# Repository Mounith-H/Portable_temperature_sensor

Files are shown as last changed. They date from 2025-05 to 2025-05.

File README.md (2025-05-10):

# Portable Temperature Sensor

<div align="center">
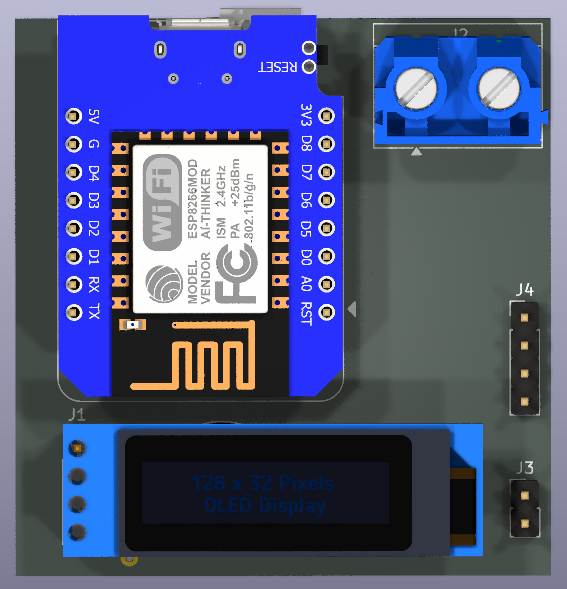
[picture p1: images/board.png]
Pin Connections Table
  
</div>



## Overview

The Portable Temperature Sensor is a wireless IoT temperature monitoring device based on the ESP8266 NodeMCU platform. It uses a MAX6675 thermocouple interface to measure temperatures up to 1024°C with high precision, making it suitable for industrial monitoring, cooking, 3D printing, and scientific applications.

### Key Features

- **High-Temperature Measurement:** Uses the MAX6675 thermocouple for accurate measurements up to 1024°C
- **Wireless Connectivity:** Built-in WiFi for remote monitoring and control
- **MQTT Support:** Integrates with home automation systems and custom dashboards
- **Alarm System:** Configurable temperature thresholds with buzzer alerts
- **Interrupt Output:** Provides digital signal output when temperature exceeds thresholds
- **Custom PCB Design:** Optimized layout with full KiCad design files
- **Serial Communication:** Both USB and software serial interfaces for flexible integration

## Hardware Components

- **NodeMCU ESP8266** - Main controller with WiFi capability
- **MAX6675 Module** - K-type thermocouple interface
- **K-Type Thermocouple** - High-temperature sensing element
- **Buzzer** - For audible alerts
- **Passive Components** - Resistors, capacitors for circuit stability

## Pin Connections

| Pin Numbers | Pin Names | Pin Function | Other | Connection |
|---|---|---|---|---|
| ADC0 | A0 | Analog Input | X | X |
| GPIO16 | D0 | WAKE | X | SEN-CS |
| GPIO5 | D1 | SCL | X | OLED/ SCL |
| GPIO4 | D2 | SDA | X | OLED/ SDA |
| GPIO0 | D3 | FLASH | Pull-up  | BUZZER |
| GPIO2 | D4 | TXD1/LED | Pull-up  | INTERRUPT |
| GPIO14 | D5 | SCLK | X | SEN-SCK |
| GPIO12 | D6 | MISO | X | SEN-SO |
| GPIO13 | D7 | MOSI/RXD2 | X | UART-RX |
| GPIO15 | D8 | CS/TXD2 | Pull-down| UART-TX |
| GPIO3 | RX | RXD0 | X | X |
| GPIO1 | TX | TXD0 | X | X |
| RST | RST | Reset | Pull-up  | X |

## Software Setup

### Prerequisites

- [PlatformIO](https://platformio.org/) (recommended) or Arduino IDE
- Required libraries:
  - PubSubClient for MQTT
  - EspSoftwareSerial for additional serial ports
  - Adafruit MAX6675 for thermocouple interface
  - GyverOLED for display support (optional - will be implemented separately)

### Installation

1. Clone this repository:
   ```
   git clone https://github.com/MOUNITH-H/Portable_temperature_sensor.git
   ```

2. Open the project in PlatformIO or Arduino IDE:
   - For PlatformIO: Open the `Portable_temperature_sensor` folder
   - For Arduino IDE: Open `src/main.cpp` as your sketch

3. Configure WiFi and MQTT settings:
   - Edit the connection parameters in `main.cpp`

4. Build and upload to your NodeMCU

## PCB Design

The project includes a custom PCB design created with KiCad. The design files are in the `pcb` folder:

- Full schematic in `pcb.kicad_sch`
- PCB layout in `pcb.kicad_pcb`
- Interactive BOM available in `pcb/bom/ibom.html`

## Usage

1. Power the device using USB or a 5V power source
2. The device will automatically connect to the configured WiFi network
3. Temperature data is published to the MQTT topic `portable_temp_sensor/temperature`
4. The buzzer will sound if the temperature exceeds the configured threshold
5. Configure alarm settings via the MQTT topic `portable_temp_sensor/settings`

## MQTT Topics

| Topic | Description | Message Format |
|---|---|---|
| `portable_temp_sensor/temperature` | Current temperature readings | `{"temp": 25.4, "timestamp": 1620123456}` |
| `portable_temp_sensor/settings` | Device configuration | `{"threshold": 80, "buzzer_enabled": true}` |
| `portable_temp_sensor/status` | Device status information | `{"uptime": 3600, "wifi_strength": -67}` |

## Troubleshooting

- **No temperature readings:** Check thermocouple connections
- **Cannot connect to WiFi:** Verify credentials in the code
- **MQTT connection issues:** Confirm server address and port settings
- **Erratic readings:** Check for interference with thermocouple wires

## TODO
- [ ] Convert to FreeRTOS

## Contributing

Contributions are welcome! Please feel free to submit a Pull Request.

## License

This project is licensed under the MIT License - see the [LICENSE](LICENSE) file for details.

## Author

- **MOUNITH H** - *Initial work*

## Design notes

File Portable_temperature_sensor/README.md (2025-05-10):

# Portable Temperature Sensor - Implementation

This folder contains the implementation code for the Portable Temperature Sensor project.

## Project Structure

```
Portable_temperature_sensor/
├── platformio.ini        # PlatformIO configuration file
├── include/              # Header files
├── lib/                  # Project-specific libraries
├── src/                  # Source code
│   ├── main.cpp          # Main application code
│   ├── NetworkManager.h  # WiFi connection management
│   ├── display_helper.h  # Display helper functions (not currently used)
│   └── display_helper.cpp# Display implementation (not currently used)
└── test/                 # Test files
```

## Development Environment

### PlatformIO Configuration

This project uses PlatformIO for dependency management and deployment. The `platformio.ini` file is configured with:

```ini
[env:nodemcuv2]
platform = espressif8266
board = nodemcuv2
framework = arduino
monitor_speed = 115200
lib_deps = 
	knolleary/PubSubClient@^2.8
	plerup/EspSoftwareSerial@^8.2.0
	adafruit/MAX6675 library@^1.1.2
	gyverlibs/GyverOLED@^1.6.4
```

> **Note:** The GyverOLED library is still included but display functionality has been removed in the latest version. This dependency will be removed in future updates.

## Implementation Details

### Hardware Configuration

The sensor hardware is configured in `main.cpp` with the following pin assignments:

```cpp
// MAX6675 thermocouple interface pins
const int thermoDO = 12;   // Data out (SO/MISO)
const int thermoCS = 16;   // Chip select
const int thermoCLK = 14;  // Clock signal

// Output pins
const int buzzerPin = 0;     // Alarm buzzer
const int interruptPin = 2;  // External trigger signal

// Software serial port
const int SOFT_RX = 13;  // GPIO13 (D7)
const int SOFT_TX = 15;  // GPIO15 (D8)
```

### Network Connectivity

WiFi connection is managed through the `NetworkManager` class in `src/NetworkManager.h`, which provides:

- Automatic reconnection handling
- Connection state management
- Status reporting

### MQTT Integration

Temperature data is published to MQTT topics, with the following features:
- Automatic reconnection to MQTT broker
- Configurable publishing interval
- JSON-formatted messages for easier parsing

## Building and Running

### Using PlatformIO

1. Open this folder in VSCode with PlatformIO extension
2. Build the project:
   ```
   platformio run
   ```
3. Upload to NodeMCU:
   ```
   platformio run --target upload
   ```
4. Monitor serial output:
   ```
   platformio device monitor
   ```

### Using Arduino IDE

1. Rename `main.cpp` to `Portable_temperature_sensor.ino`
2. Install required libraries through the Arduino Library Manager
3. Set board to "NodeMCU 1.0 (ESP-12E Module)"
4. Upload sketch

## Configuration

To configure the device, edit the following parameters in `src/main.cpp`:

```cpp
// WiFi settings
const char* ssid = "YOUR_WIFI_SSID";
const char* password = "YOUR_WIFI_PASSWORD";

// MQTT settings
const char* mqtt_server = "YOUR_MQTT_SERVER";
const int mqtt_port = 1883;

// Temperature thresholds
const float tempThreshold = 80.0;  // Temperature alarm threshold in °C
```

## Known Issues

1. After power loss, device requires manual configuration

---

For full project documentation, including hardware details and usage instructions, see the [main README](../README.md) in the parent directory.

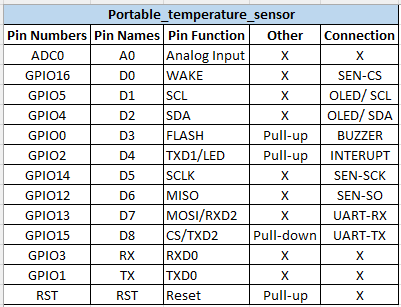
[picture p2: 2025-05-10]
images/Connections_Table.png

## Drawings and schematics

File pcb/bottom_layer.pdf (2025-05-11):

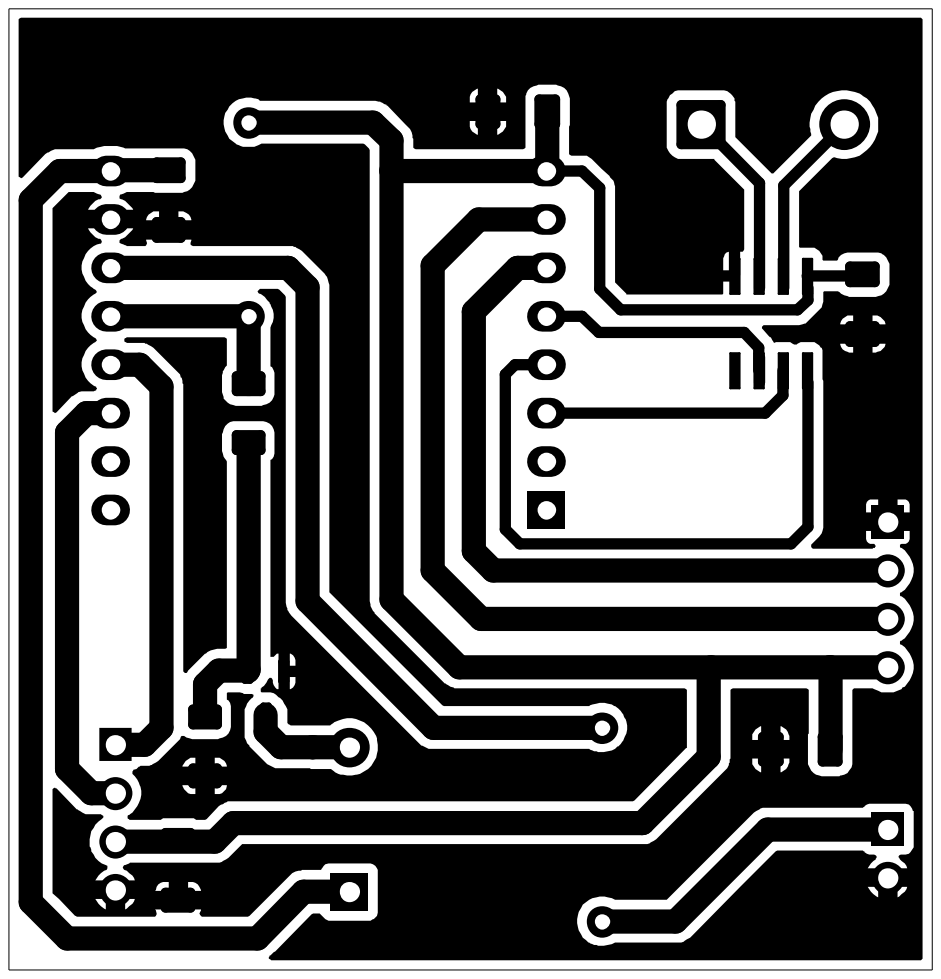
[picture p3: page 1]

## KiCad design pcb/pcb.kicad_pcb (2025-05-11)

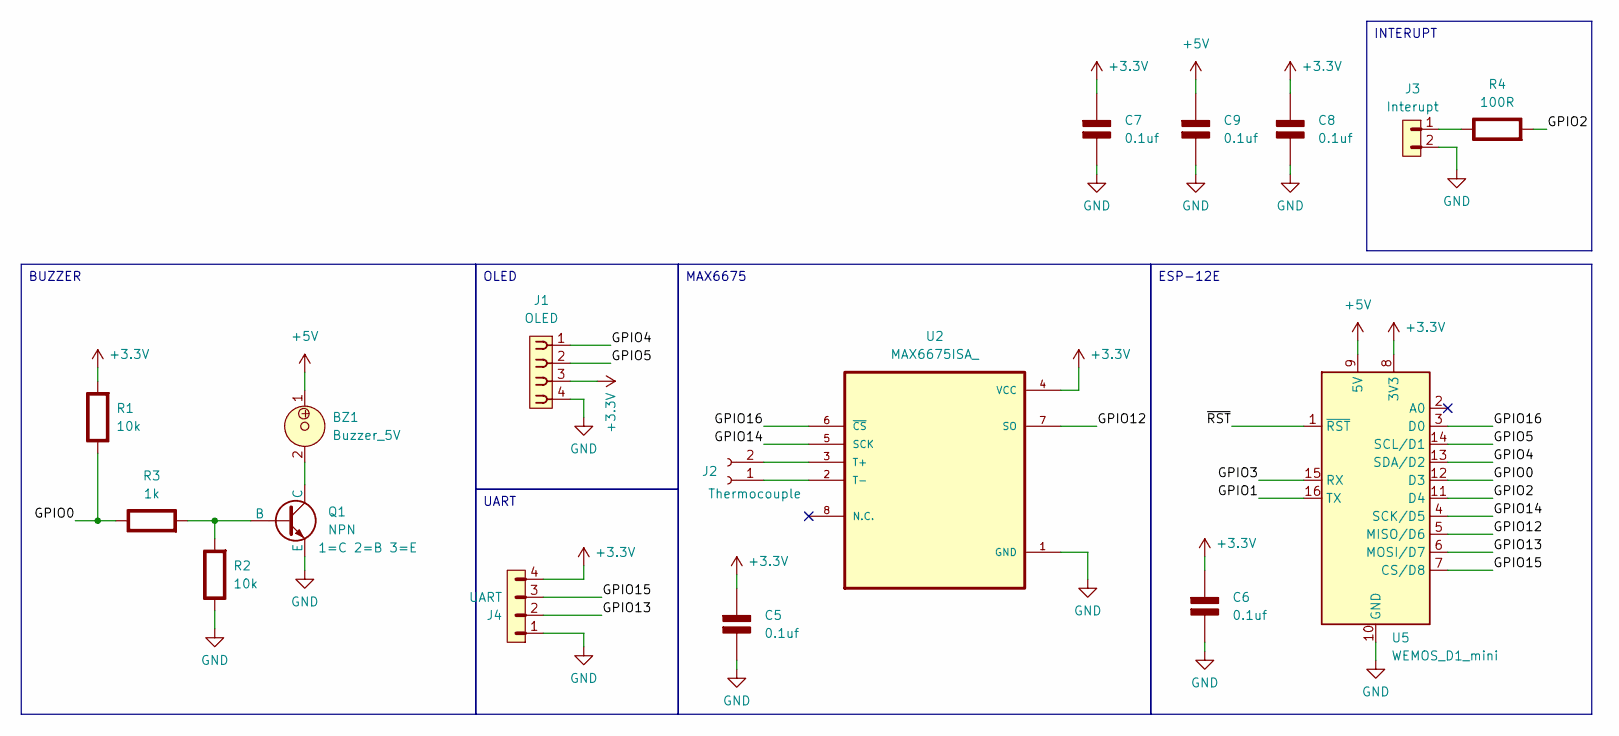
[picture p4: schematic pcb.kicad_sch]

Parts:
BZ1: Buzzer_5V; Buzzer_12x9.5RM7.6
C5, C6, C7, C8, C9: 0.1uf; C_1206_3216Metric_Pad1.33x1.80mm_HandSolder; Rating V
J1: OLED; PinSocket_1x04_P2.54mm_Vertical
J2: Thermocouple; TerminalBlock_MetzConnect_Type175_RT02702HBLC_1x02_P7.50mm_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
J3: Interupt; PinHeader_1x02_P2.54mm_Vertical
J4: UART; PinHeader_1x04_P2.54mm_Vertical
Q1: NPN; SOT-23-3
R1: 10k; R_Axial_DIN0207_L6.3mm_D2.5mm_P10.16mm_Horizontal; Rating W
R2: 10k; R_1206_3216Metric_Pad1.30x1.75mm_HandSolder; Rating W
R3: 1k; R_1206_3216Metric_Pad1.30x1.75mm_HandSolder; Rating W
R4: 100R; R_Axial_DIN0207_L6.3mm_D2.5mm_P10.16mm_Horizontal; Rating W
U2: MAX6675ISA_; MAX6675ISA__SOIC127P600X175-8N
U5: WEMOS_D1_mini; WEMOS_D1_mini_light

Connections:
+3.3V: C5.1 (+), C6.1 (+), C7.1 (+), C8.1 (+), J1.3, J4.4, R1.2 (-), U2.4 (VCC), U5.8 (3V3)
+5V: BZ1.1, C9.1 (+), U5.9 (5V)
/GPIO0: R1.1 (+), R3.1 (+), U5.12 (D3)
/GPIO1: U5.16 (TX)
/GPIO2: R4.2 (-), U5.11 (D4)
/GPIO3: U5.15 (RX)
/GPIO4: J1.1, U5.13 (SDA/D2)
/GPIO5: J1.2, U5.14 (SCL/D1)
/GPIO12: U2.7 (SO), U5.5 (MISO/D6)
/GPIO13: J4.2, U5.6 (MOSI/D7)
/GPIO14: U2.5 (SCK), U5.4 (SCK/D5)
/GPIO15: J4.3, U5.7 (CS/D8)
/GPIO16: U2.6 (~CS), U5.3 (D0)
/~RST: U5.1 (~RST)
GND: C5.2 (-), C6.2 (-), C7.2 (-), C8.2 (-), C9.2 (-), J1.4, J3.2, J4.1, Q1.3 (E), R2.1 (+), U2.1 (GND), U5.10 (GND)
unnamed: J2.1, U2.2 (T-)
unnamed: J2.2, U2.3 (T+)
unnamed: Q1.2 (B), R2.2 (-), R3.2 (-)
unnamed: BZ1.2, Q1.1 (C)
unnamed: J3.1, R4.1 (+)

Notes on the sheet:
UART
BUZZER
MAX6675
INTERUPT
ESP-12E
OLED

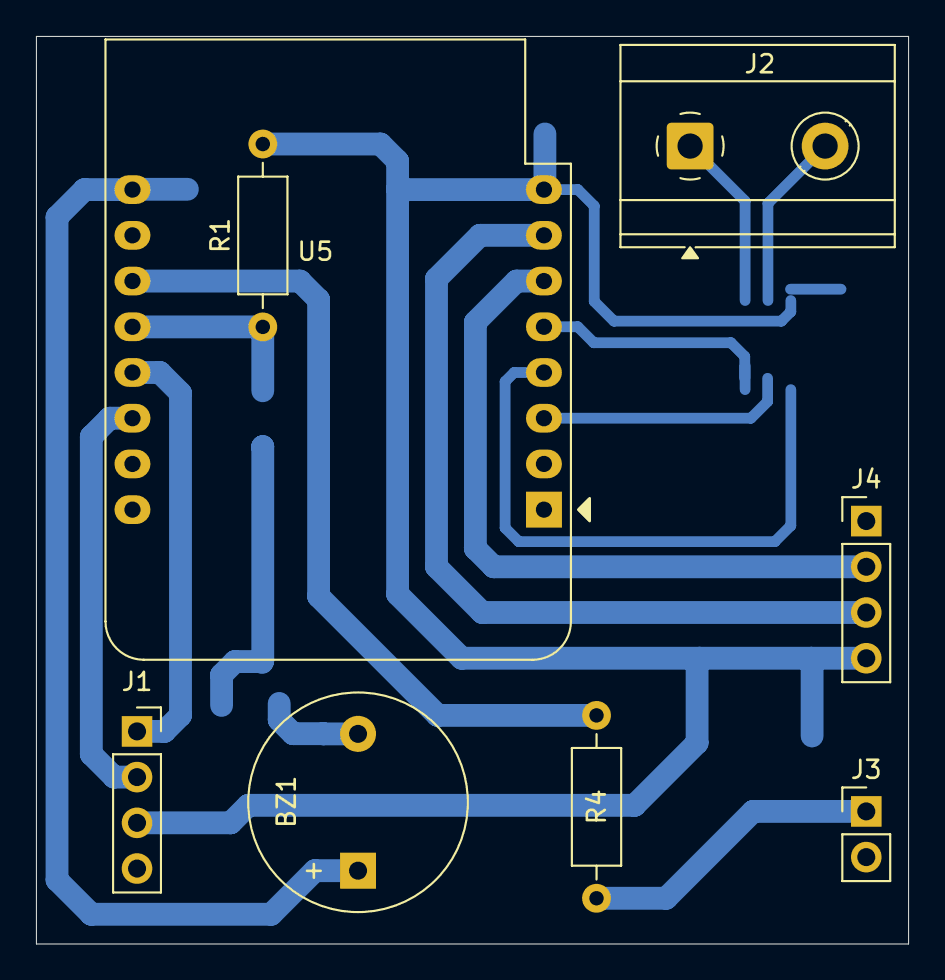
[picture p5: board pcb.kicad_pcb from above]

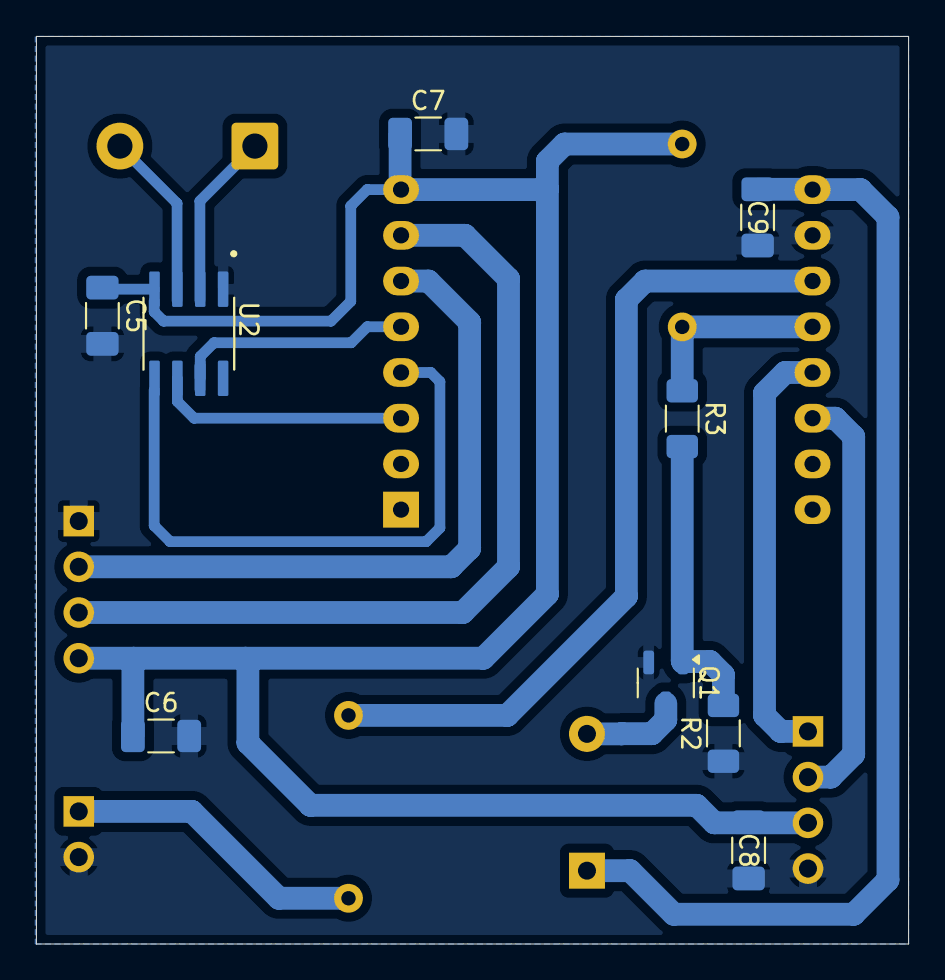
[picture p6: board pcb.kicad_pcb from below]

Board: 2 copper layers, 48.5 x 50.4 mm, 17 parts (9 on the bottom side), 17 nets.

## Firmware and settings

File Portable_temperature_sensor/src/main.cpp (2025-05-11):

#include <Arduino.h>
#include <ESP8266WiFi.h>
#include <PubSubClient.h>
#include <SoftwareSerial.h>
#include <time.h>
#include <max6675.h>
#include <GyverOLED.h>
#include "NetworkManager.h"
#include "display_helper.h"
#include "splashScreen.h"

/*
HARDWARE CONNECTIONS:

MAX6675 Thermocouple:
- SO  → GPIO12 (D6)  // Data from sensor
- CS  → GPIO16 (D0)  // Chip select
- SCK → GPIO14 (D5)  // Clock signal

OLED Display (I2C):
- SDA → GPIO4  (D2)
- SCL → GPIO5  (D1)

Peripherals:
- Buzzer   → GPIO0  (D3)  // Alarm when temperature exceeds threshold
- Interrupt → GPIO2  (D4)  // External trigger signal

Communication:
- Software Serial: RX→GPIO13 (D7), TX→GPIO15 (D8)  // For external comms
- Hardware Serial: USB port (115200 baud)          // For debugging

Power Requirements:
- All components operate at 3.3V
- Connect all GND pins to common ground
*/

// External communication port (separate from debug serial)
const int SOFT_RX = 13;  // GPIO13 (D7)
const int SOFT_TX = 15;  // GPIO15 (D8)
SoftwareSerial softSerial(SOFT_RX, SOFT_TX);

// MAX6675 thermocouple interface pins
const int thermoDO = 12;   // Data out (SO/MISO)
const int thermoCS = 16;   // Chip select
const int thermoCLK = 14;  // Clock signal
MAX6675 thermocouple(thermoCLK, thermoCS, thermoDO);

// Output pins
const int buzzerPin = 0;     // Alarm buzzer
const int interruptPin = 2;  // External trigger signal

// Wi-Fi & MQTT configuration (fill these in)
const char* ssid         = "********";        // FIXME: replace with your wifi SSID
const char* password     = "********";        // FIXME: replace with your wifi password
const char* mqtt_server  = "192.168.137.1";   // FIXME: replace with your mqtt server IP
const int   mqtt_port    = 1883;              // replace with your mqtt server port default is 1883
const char* mqtt_user    = "***test***";      // FIXME: replace with your mqtt username
const char* mqtt_pass    = "***test***";      // FIXME: replace with your mqtt password

WiFiClient espClient;
PubSubClient mqttClient(espClient);
NetworkManager networkManager(ssid, password);

// OLED display definitions (I2C PCB: SDA=GPIO4, SCL=GPIO5)
#define SCREEN_WIDTH 128
#define SCREEN_HEIGHT 32
#define OLED_WHITE 1  // Color constant for drawing in white
#define OLED_BLACK 0  // Color constant for drawing in black
int currentX, currentY, currentScale; // Track cursor position and text scale

// Initialize OLED display with SSD1306 driver (128x32 resolution)
// using buffered mode for smoother updates, at I2C address 0x3C
GyverOLED<SSD1306_128x32, OLED_BUFFER> display(0x3C);

// OLED Display Settings
unsigned long mainDisplayUpdateInterval = 1000; // Update display every 1 second
unsigned long mainLastDisplayUpdateInterval = 0;

// Battery voltage monitoring 
float batteryVoltage = 0.0; // Battery voltage in volts
int batteryPercentage = 0.0; // Battery percentage (0-100%)
unsigned long lastBatteryUpdate = 0;
const unsigned long batteryUpdateInterval = 1000; // Update battery status every 1 seconds
bool batteryIndicatorToggle = false; // Flag to toggle battery indicator on display

// WiFi and MQTT state tracking
bool mqttWasConnected = false;
unsigned long lastDisplayUpdate = 0;
const unsigned long displayUpdateInterval = 500; // Update network status on display every 1 seconds
bool updateDisplayStatus = false;

// Time configuration
const char* ntpServer = "pool.ntp.org";
const long  gmtOffset_sec = 19800;  // GMT +5:30 for IST // FIXME: Update gmt offset of your location
const int   daylightOffset_sec = 0;
String outputMode = "normal";  // Default output mode

// Data configuration
unsigned long sendInterval  = 1000; // ms between sends
double        thresholdTemp = 80.00;   // °C setpoint
unsigned long lastSendTime  = 0;

// Buzzer control
bool buzzerEnabled = true;        // Global flag to enable/disable buzzer
unsigned long buzzerSilenceUntil = 0;  // Timestamp until when the buzzer should be silenced

// MQTT activity tracking
unsigned long lastMqttUpload = 0;    // Last time data was uploaded
unsigned long lastMqttDownload = 0;  // Last time data was downloaded
const unsigned long mqttActivityIndicatorDuration = 100; // How long to show upload/download activity (ms)

// Global variables
static double tempValue = 0;
bool otherUpdate = true;

// Forward declarations
void mqttCallback(char* topic, byte* payload, unsigned int length);
bool mqttReconnect(int maxAttempts = 3);
void playBuzzerAlarm(double temperature, double threshold); // Control buzzer based on temperature
void updateNetworkDisplay(); // Update network status on display
void logodisplay(); // Display logo on OLED
void displayUpdate(); // Update display with temperature and settings
void serialHandler(); // Handle incoming serial data
void batteryMonitor(); // Monitor battery voltage

void setup() {  
  // Initialize both serial ports
  Serial.begin(115200);     // Hardware Serial for debug
  softSerial.begin(9600);   // Software Serial for communication with external device
  Serial.println("Debug: Serial ports initialized");
  
  // Configure output pins for buzzer and interrupt signals
  pinMode(buzzerPin, OUTPUT);
  pinMode(interruptPin, OUTPUT);
  digitalWrite(interruptPin, LOW); // Initialize interrupt signal as inactive
  
  noTone(buzzerPin);              // Initialize buzzer in silent state
  // MAX6675 automatically initializes when the object is created
  // I2C init for OLED
  Wire.begin(4, 5);
  Wire.setClock(400000);  // Set I2C clock speed to 400kHz (fast mode)
  display.init();                 // Initialize the display
  display.clear();                // Clear the display buffer - necessary to start with a clean black background
  display.setScale(1);            // Set text size scaling to 1 (equivalent to setTextSize)
  display.autoPrintln(true);      // Enable automatic line breaks
  display.invertText(false);      // Ensure text isn't inverted (text is white on black background)
  display.textMode(BUF_REPLACE);  // Ensure text writes in replace mode (not overlaid)

  logodisplay();  // Display animated logo on OLED

  // Initialize network manager (non-blocking)
  networkManager.begin();
  networkManager.startConnection();  // Define version and device info
  const String VERSION = "1.1.0";
  const String DEVICE_ID = "ESP-" + String(ESP.getChipId(), HEX);

  // Show startup message
  display.clear();
  display.setScale(2);
  display.setCursor(57, 0);
  display.print("MEL");
  display.setScale(1);
  display.setCursor(0, 2);
  display.print("Temp Sensor v");
  display.print(VERSION);
  display.setCursor(0, 3); // line 1 (GyverOLED uses line-based cursor position)
  display.print("ID: ");
  display.print(DEVICE_ID);
  display.update(); // update display (equivalent to display.display())

  // Print startup info to Serial  
  Serial.println("\n=========================");
  Serial.println("Temperature Sensor v" + VERSION);
  Serial.println("Device ID: " + DEVICE_ID);
  Serial.println("Sensor: MAX6675 (Digital)");
  Serial.println("Connecting to WiFi: " + String(ssid));
  Serial.println("MQTT Server: " + String(mqtt_server) + ":" + String(mqtt_port));
  
  // Test MAX6675 reading
  float initialTemp = thermocouple.readCelsius();
  Serial.print("Initial temperature reading: ");
  Serial.print(initialTemp);
  Serial.println("°C");
  Serial.println("=========================");
  
  // Configure time (it will sync once WiFi is available)
  configTime(gmtOffset_sec, daylightOffset_sec, ntpServer);
  
  // MQTT setup (connection will happen in loop)
  mqttClient.setServer(mqtt_server, mqtt_port);
  mqttClient.setCallback(mqttCallback);

  delay(1500);
  display.clear();
  display.line(0,16,128,16,OLED_WHITE);
  display.update(); // Clear display after startup message
}

// Update network status display without blocking
// Shows connection status and activity indicators through small dots on display
void updateNetworkDisplay() {
  // MQTT upload activity indicator in top-right corner (data sent to broker)
  if (millis() - lastMqttUpload < mqttActivityIndicatorDuration) {display.dot(127, 0, OLED_WHITE); display.update(127, 0, 127, 0);} 
  else {display.dot(127, 0, OLED_BLACK);  display.update(127, 0, 127, 0);} 

  // Return if it's not time for the next status update
  if (millis() - lastDisplayUpdate < displayUpdateInterval) {
   return;  // Not time to update yet
  }
  lastDisplayUpdate = millis();
  updateDisplayStatus = !(updateDisplayStatus);  // Toggle blink state

  ConnectionState state = networkManager.getState();
  bool mqttConnected = mqttClient.connected();
  
  // Make sure we're not overlapping with other display operations
  display.textMode(BUF_REPLACE);  // Ensure text writes in replace mode (not overlaid)

  // Draw the status indicators one by one
  // MQTT status indicator
  if (mqttConnected) {
    display.dot(127, 4, OLED_WHITE);  // MQTT dot
  } else if (state == CONN_CONNECTED) {
    // MQTT disconnected but WiFi connected - blink
    if (!updateDisplayStatus) display.dot(127, 4, OLED_BLACK); 
    else display.dot(127, 4, OLED_WHITE); 
  } else if ((state == CONN_DISCONNECTED) || (state == CONN_CONNECTION_FAILED)) display.dot(127, 4, OLED_BLACK);

  // WiFi status indicator
  if (state == CONN_CONNECTED) {
    display.dot(127, 8, OLED_WHITE);  // WiFi dot
  } else if (state == CONN_CONNECTING) {
    // Blinking WiFi indicator 
    if (!updateDisplayStatus) display.dot(127, 8, OLED_BLACK); 
    else display.dot(127, 8, OLED_WHITE); 
  } else if ((state == CONN_DISCONNECTED) || (state == CONN_CONNECTION_FAILED)) display.dot(127, 8, OLED_BLACK);

  // Use partial update to only refresh the status indicator area
  display.update(127, 4, 127, 8);  // Update only the status indicator region
  
}

// Non-blocking MQTT reconnect helper
#define CLIENT_ID_LEN 24
bool mqttReconnect(int maxAttempts) {
  if (!networkManager.isConnected()) {
    return false;  // Can't connect to MQTT without WiFi
  }

  static int attempts = 0;
  static unsigned long lastAttemptTime = 0;
  const unsigned long attemptInterval = 1000;  // 1 second between attempts
  
  if (!mqttClient.connected()) {
    unsigned long now = millis();
    
    if (now - lastAttemptTime > attemptInterval) {
      lastAttemptTime = now;
      
      if (attempts < maxAttempts) {
        Serial.print("Debug: MQTT attempt ");
        Serial.println(attempts + 1);
        
        char clientId[CLIENT_ID_LEN];
        snprintf(clientId, CLIENT_ID_LEN, "NodeMCU-%lu", millis());
        if (mqttClient.connect(clientId, mqtt_user, mqtt_pass)) {
          mqttClient.subscribe("sensor/interval");
          mqttClient.subscribe("sensor/setpoint");
          mqttClient.subscribe("sensor/buzzer");  // Add buzzer control topic
          attempts = 0;  // Reset counter on success
          return true;
        } else {
          Serial.print("MQTT connection failed, state=");
          Serial.print(mqttClient.state());
          Serial.print(", attempt ");
          Serial.print(attempts + 1);
          Serial.print("/");
          Serial.println(maxAttempts);
          attempts++;
        }
      } else {
        attempts = 0;  // Reset for next time
        return false;
      }
    }
  } else {
    attempts = 0;  // Reset counter when connected
    return true;
  }
  
  return false;
}

// Main program loop - handles network, display, serial commands, and sensor readings
// Uses non-blocking approach to ensure responsive operation
void loop() {
  // Core functionality handling
  networkManager.update();    // Update network state (non-blocking)
  updateNetworkDisplay();     // Update network status on display (non-blocking)
  serialHandler();            // Handle incoming serial data (non-blocking)
  batteryMonitor();           // Monitor battery voltage (non-blocking)
  // Check if WiFi just connected and print status
  if (networkManager.justConnected()) {
    Serial.println("\n=========================");
    Serial.print("WiFi CONNECTED to: ");
    Serial.println(ssid);
    Serial.print("IP address: ");
    Serial.println(networkManager.getLocalIP());
    Serial.println("=========================");
  }
  
  // MQTT connection management (only if WiFi connected)
  if (networkManager.isConnected()) {
    if (!mqttClient.connected()) {
      // Try reconnect without blocking if not connected
      if (!mqttWasConnected || (millis() % 10000) < 10) {  // First connect or try every ~10 seconds
        bool justConnected = mqttReconnect(1);  // Quick single attempt
        
        // Check if MQTT just connected and print status
        if (justConnected && !mqttWasConnected) {          Serial.println("\n=========================");
          Serial.print("MQTT CONNECTED to broker: ");
          Serial.print(mqtt_server);
          Serial.print(":");
          Serial.println(mqtt_port);
          Serial.println("Subscribed to sensor/interval, sensor/setpoint, and sensor/buzzer");
          Serial.println("Publishing to sensor/temperature");
          Serial.println("MQTT activity indicators: TX (↑), RX (↓) in display corners");
          Serial.println("=========================");
        }
        
        mqttWasConnected = justConnected;
      }
    } else {
      mqttClient.loop();
      
      // If MQTT just became connected
      if (!mqttWasConnected) {
        Serial.println("\n=========================");
        Serial.println("MQTT connection restored");
        Serial.println("=========================");
        mqttWasConnected = true;
      }
    }  
  } 
  else if (mqttWasConnected) {
    Serial.println("\n=========================");
    Serial.println("MQTT DISCONNECTED (WiFi lost)");
    Serial.println("=========================");
    mqttWasConnected = false;  // Reset when WiFi disconnects
  }

  // Store latest temperature reading
  static double tempC = 0.0;
  
  // Periodic temperature read & send
  unsigned long now = millis();
  if (now - lastSendTime >= sendInterval) {
    lastSendTime = now;
      
    // Read MAX6675 temperature
    tempC = thermocouple.readCelsius();  // Direct reading in Celsius
    tempValue = tempC;
    // Get current time (for timestamping in log mode)
    time_t now;
    struct tm timeinfo;
    time(&now);
    localtime_r(&now, &timeinfo);

    // Format and send output based on mode    
    if (outputMode.equals("log")) {
      softSerial.printf("%02d,%02d,%04d,%02d,%02d,%02d,%.2f\n",
                        timeinfo.tm_mday,
                        timeinfo.tm_mon + 1,
                        timeinfo.tm_year + 1900,
                        timeinfo.tm_hour,
                        timeinfo.tm_min,
                        timeinfo.tm_sec,
                        tempC);
    } else if(outputMode.equals("normal")) {
      softSerial.printf("%.2f\n", tempC);
    }    
    
    if (networkManager.isConnected() && mqttClient.connected()) {
      char buf[16];
      dtostrf(tempC, 0, 1, buf);
      
      // Publish temperature and update upload indicator      
      if (mqttClient.publish("sensor/temperature", buf)) {
        lastMqttUpload = millis(); // Mark upload activity time
      }    
    }
      // Control buzzer and interrupt pin based on temperature    
    playBuzzerAlarm(tempC, thresholdTemp);
  }

  displayUpdate();            // Update display 
}

// Handle incoming serial commands from both software and hardware serial
void serialHandler() {
  if (softSerial.available() || Serial.available()) {
    // Read from Software Serial if available, else from Hardware Serial
    String cmd = (softSerial.available()) ? softSerial.readStringUntil('\n') : Serial.readStringUntil('\n');
    cmd.trim(); 
    Serial.print("Command:");
    Serial.println(cmd);   

    if (cmd.equals("log")) {
      outputMode = "log";
      Serial.println("Debug: Switched to Log mode");
    } 
    else if (cmd.equals("normal")) {
      outputMode = "normal";
      Serial.println("Debug: Switched to Normal mode");
    } 
    else if (cmd.startsWith("interval")) {
      unsigned long v = cmd.substring(9).toInt();
      if (v > 0) {
        sendInterval = v;
        Serial.printf("Debug: Interval set to %lums\n", sendInterval);
      }    
    } 
    else if (cmd.startsWith("oled")) {
      unsigned long v = cmd.substring(5).toInt();
      if (v > 0) {
        mainDisplayUpdateInterval = v;
        Serial.printf("Debug: oled update interval set to %lums\n", mainDisplayUpdateInterval);
      }
    } 
    else if (cmd.startsWith("setpoint")) {
      double v = cmd.substring(9).toFloat();
      thresholdTemp = v;
      Serial.printf("Debug: Setpoint set to %.1f°C\n", thresholdTemp);    
    } 
    else if (cmd.startsWith("buzzer")) {
      unsigned int v = cmd.substring(7).toInt();
      Serial.println("Debug: Buzzer command received: " + String(v));
      buzzerEnabled = (v==1?true:false);
      if (buzzerEnabled) Serial.println("Debug: Buzzer enabled");
      else 
      {
        noTone(buzzerPin);  // Ensure buzzer is silent
        Serial.println("Debug: Buzzer disabled");
      }
    } 
    else if (cmd.startsWith("silence")) {      
      unsigned long duration = cmd.substring(8).toInt();
      buzzerSilenceUntil = millis() + duration * 1000UL; // Convert seconds to seconds 
      Serial.printf("Debug: Buzzer silenced for %luS\n", duration);
    } 
    else if (cmd == "reset") {
      Serial.println("Debug: Reset requested (display functionality removed)");
    }
    otherUpdate = true;
  }
}

// Update OLED display with current temperature and status information
void displayUpdate() {
  if((millis() - mainLastDisplayUpdateInterval) > mainDisplayUpdateInterval) {
    mainLastDisplayUpdateInterval = millis();
    
    // First update the top part (temperature)
    display.textMode(BUF_REPLACE);
    display.clear(0, 0, 126, 15);
    display.setScale(2);
    display.setCursor(0, 0);
    display.printf("%.2fC", tempValue);
    display.update(0, 0, 126, 15);
    
    // Then update the bottom part if needed
    if(otherUpdate) {
      otherUpdate = false;

      display.rect(0, 17, 126, 31, OLED_BLACK);
      display.setScale(1);
      display.setCursor(0, 3);
      display.printf("SET:%0.2fC", thresholdTemp);
      display.setCursor(72, 3);
      display.printf("|%s |%s", (outputMode.equals("log")?"LOG":"NRM"), (buzzerEnabled?"ON":"OFF"));
      display.update(0, 17, 126, 31);
    }
  }
}

// Controls buzzer based on temperature threshold
// Generates variable pitch based on how much temperature exceeds threshold
void playBuzzerAlarm(double temperature, double threshold) {
  if (buzzerEnabled && temperature > threshold) {
    // Map temp to frequency range (1000-2000Hz): higher temp = higher pitch
    int freq = map(temperature, threshold + 5, 100, 1000, 2000);
    tone(buzzerPin, freq);
  } else {
    noTone(buzzerPin);
  }
}

// MQTT message callback - processes incoming commands from broker
// Handles settings updates (interval, setpoint) and buzzer control commands
void mqttCallback(char* topic, byte* payload, unsigned int length) {
  // Mark activity time for download indicator on display
  lastMqttDownload = millis();
  
  // Debug output to serial console
  Serial.print("MQTT message arrived [");
  Serial.print(topic);
  Serial.print("]: ");
  
  // Convert binary payload to string for easier handling
  String message;
  for (unsigned int i = 0; i < length; i++) {
    char c = (char)payload[i];
    Serial.print(c);
    message += c;
  }
  Serial.println();
    // Handle specific topics
  if (String(topic).equals("sensor/interval")) {
    unsigned long interval = message.toInt();
    if (interval > 0) {
      sendInterval = interval;
      Serial.printf("Send interval updated to %lu ms\n", sendInterval);
    }
  }
  else if (String(topic).equals("sensor/setpoint")) {
    double setpoint = message.toFloat();
    thresholdTemp = setpoint;
    Serial.printf("Temperature setpoint updated to %.1f°C\n", thresholdTemp);
    } else if (String(topic).equals("sensor/buzzer")){
    // Buzzer control message - format: "on", "off", "silence <seconds>"
    if (message.equals("on")) {
      buzzerEnabled = true;
      Serial.println("Buzzer enabled");
    } else if (message.equals("off")) {
      buzzerEnabled = false;
      noTone(buzzerPin);
      Serial.println("Buzzer disabled");
    } else if (message.startsWith("silence")) {
      int seconds = message.substring(8).toInt();
      if (seconds > 0) {
        buzzerSilenceUntil = millis() + seconds * 1000UL;
        Serial.printf("Buzzer silenced for %d seconds\n", seconds);
        noTone(buzzerPin);  // Immediately silence
      }
    }
  }
  otherUpdate = true;
}
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

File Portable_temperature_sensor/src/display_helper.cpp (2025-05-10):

#include "display_helper.h"
#include "NetworkManager.h"

// External variables defined elsewhere
extern GyverOLED<SSD1306_128x32, OLED_BUFFER> display;
extern int currentX; // Current cursor position X
extern int currentY; // Current cursor position Y
extern int currentScale; // Current text scale

// Function to set text cursor position
void setTextCursor(int x, int y) {
  display.setCursor(x, y);
  currentX = x;
  currentY = y;
}

// Function to set text scale
void setTextScale(int scale) {
  display.setScale(scale);
  currentScale = scale;
}

// Function to print text (const char* version) 
void printText(const char* text) {
  // Skip any leading spaces (which otherwise show as white rectangles)
  const char* ptr = text;
  while (*ptr == ' ') ptr++;
  
  // Get current position from our tracking variables
  int x = currentX;
  int y = currentY;
  int scale = currentScale;  // Use the current text scale
  
  // Print the text character by character, skipping spaces
  while (*ptr) {
    if (*ptr != ' ') {
      // Save current position
      display.setCursor(x, y);
      display.print(*ptr);
      x += 6 * scale; // Move forward to character width (6 pixels * scale)
    } else {
      // For spaces, just move the cursor forward
      x += 6 * scale; // Space width (same as character width)
    }
    ptr++;
  }
  
  // Update our position tracking
  currentX = x;
  currentY = y;
}

// Function to print text (String version)
void printText(const String& text) {
  printText(text.c_str());
}

// Function to display temperature with specific formatting
void displayTemperature(double value, int x, int y, int scale, bool addDegreeSymbol) {
  // Format temperature to one decimal place
  char tempStr[10];
  sprintf(tempStr, "%.1f", value);
  
  // Set cursor and scale
  setTextCursor(x, y);
  setTextScale(scale);
  
  // Print formatted temperature
  display.print(tempStr);
  
  // Add degree symbol if requested
  if (addDegreeSymbol) {
    int strWidth = strlen(tempStr) * 6 * scale; // Approximate width
    
    // Add degree symbol
    setTextScale(scale > 1 ? scale - 1 : 1); // Smaller scale for symbol
    display.setCursor(x + strWidth, y);
    display.print((char)247); // ° symbol
    display.print("C");
    
    // Restore original scale
    setTextScale(scale);
  }
}

// This helper function will directly handle temperature display in the left half of the screen
void drawTemperatureScreen(double temperature, double setpoint, bool buzzerEnabled, unsigned long silenceUntil, String mode) {
  // Debug the temperature value to serial
  Serial.print("DEBUG: Drawing temperature screen with temp=");
  Serial.println(temperature);
  
  // Ensure the display is initialized properly before clearing
  display.clear();   // Clear the buffer
  display.update();  // Initial update to ensure the display is clear
  display.clear();   // Clear again for good measure
  
  // Draw vertical divider in the middle of the screen
  display.line(SCREEN_WIDTH/2, 0, SCREEN_WIDTH/2, SCREEN_HEIGHT-1, 1);
  
  // LEFT SIDE - Temperature display
  char tempStr[8];
  sprintf(tempStr, "%.1f", temperature);
  
  // MAXIMUM VISIBILITY APPROACH
  // Create a black filled rectangle for temperature display (white outline on black)
  for (int y = 2; y < SCREEN_HEIGHT-2; y++) {
    for (int x = 2; x < SCREEN_WIDTH/2-2; x++) {
      display.dot(x, y, 0); // Fill with black (0)
    }
  }
  
  // Draw border around temperature area (white border)
  display.rect(1, 1, SCREEN_WIDTH/2-2, SCREEN_HEIGHT-2, 1); 
  
  // Set text to be normal (white on black), which is default
  // Use a clearly visible scale for temperature
  display.setScale(2);  
  
  // Fixed positioning that works reliably
  int tempLength = strlen(tempStr);
  int charWidth = 12; // Width of each digit at scale 2
  
  // Center horizontally in the left half
  int centerX = (SCREEN_WIDTH/2 - tempLength * charWidth) / 2;
  if (centerX < 4) centerX = 4; // Minimum margin
  
  // Center vertically
  int centerY = (SCREEN_HEIGHT - 16) / 2; // 16 is approximate height of scale 2 text
  
  // DEBUG - print positioning information
  Serial.print("Temp string: ");
  Serial.print(tempStr);
  Serial.print(", length: ");
  Serial.print(tempLength);
  Serial.print(", position X: ");
  Serial.print(centerX);
  Serial.print(", Y: ");
  Serial.println(centerY);
  
  // Draw temperature
  display.setCursor(centerX, centerY);
  display.print(tempStr);
  
  // Add degree symbol and C with appropriate scale
  display.setScale(1); // Smaller scale for the symbols
  display.setCursor(centerX + (tempLength * charWidth), centerY + 2);
  display.print((char)247); // ° symbol
  display.setCursor(centerX + (tempLength * charWidth) + 6, centerY + 2);
  display.print('C');
  
  // Reset text to normal (black on white background) for the right side of screen
  display.invertText(false);
  
  // RIGHT SIDE - Parameters
  // Set threshold
  display.setScale(1);
  display.setCursor(SCREEN_WIDTH/2 + 3, 2);
  display.print("SET:");
  display.setCursor(SCREEN_WIDTH/2 + 25, 2);
  
  // Format setpoint
  char setStr[8];
  sprintf(setStr, "%.1f", setpoint);
  display.print(setStr);
  display.print((char)247); // Degree symbol
  display.print("C");
  
  // Add horizontal dividers on right side
  display.line(SCREEN_WIDTH/2+1, 12, SCREEN_WIDTH-1, 12, 1);
  
  // Buzzer status
  display.setCursor(SCREEN_WIDTH/2 + 3, 15);
  display.print("BUZ:");
  display.setCursor(SCREEN_WIDTH/2 + 25, 15);
  if (!buzzerEnabled) {
    display.print("OFF");
  } else if (millis() < silenceUntil) {
    display.print("MUTE");
  } else {
    display.print("ON");
  }
    // Mode indicator
  display.line(SCREEN_WIDTH/2+1, 24, SCREEN_WIDTH-1, 24, 1);
  display.setCursor(SCREEN_WIDTH/2 + 3, 26);
  display.print("MODE:");
  display.setCursor(SCREEN_WIDTH/2 + 32, 26);
  if (mode.equals("log")) {
    display.print("LOG");
  } else {
    display.print("NRM");
  }
  
  // Connection status indicators in the corners
  // WiFi indicator (bottom left)
  display.setCursor(2, SCREEN_HEIGHT-8);  if (networkManager.isConnected()) {
    display.print("W");
  } else if (networkManager.getState() == ConnectionState::CONN_CONNECTING) {
    if ((millis() / 500) % 2) {
      display.print("W");
    }
  } else {
    display.print("X");
  }
  
  // MQTT indicator (bottom right)
  display.setCursor(SCREEN_WIDTH-8, SCREEN_HEIGHT-8);
  if (mqttClient.connected()) {
    display.print("M");
  } else if (networkManager.isConnected()) {
    if ((millis() / 500) % 2) {
      display.print("M");
    }
  } else {
    display.print("X");
  }
  
  // Draw MQTT activity indicators in the top corners
  // Upload indicator (top left corner)
  if (millis() - lastMqttUpload < mqttActivityIndicatorDuration) {
    // Draw a simple arrow with lines instead of triangle
    display.line(5, 0, 5, 3, 1);   // Vertical line
    display.line(3, 2, 5, 0, 1);   // Left diagonal
    display.line(7, 2, 5, 0, 1);   // Right diagonal
  }
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

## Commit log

2025-05-10 edited Portable_temperature_sensor README
    [pcb.kicad_pcb]
2025-05-10 fixed network status indicators in oled
    [main.cpp]
2025-05-10 updated changes in pcb
    [pcb.kicad_pcb, pcb.kicad_sch]
2025-05-11 added battery functionality, updated pcb
    [pcb.kicad_pcb, pcb.kicad_sch]

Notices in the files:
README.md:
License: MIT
